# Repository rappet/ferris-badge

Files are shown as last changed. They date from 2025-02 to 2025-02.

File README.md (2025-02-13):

# Ferris STM32L0 badge

Small badge running on a coin cell using a STM32L031G6U with embassy.

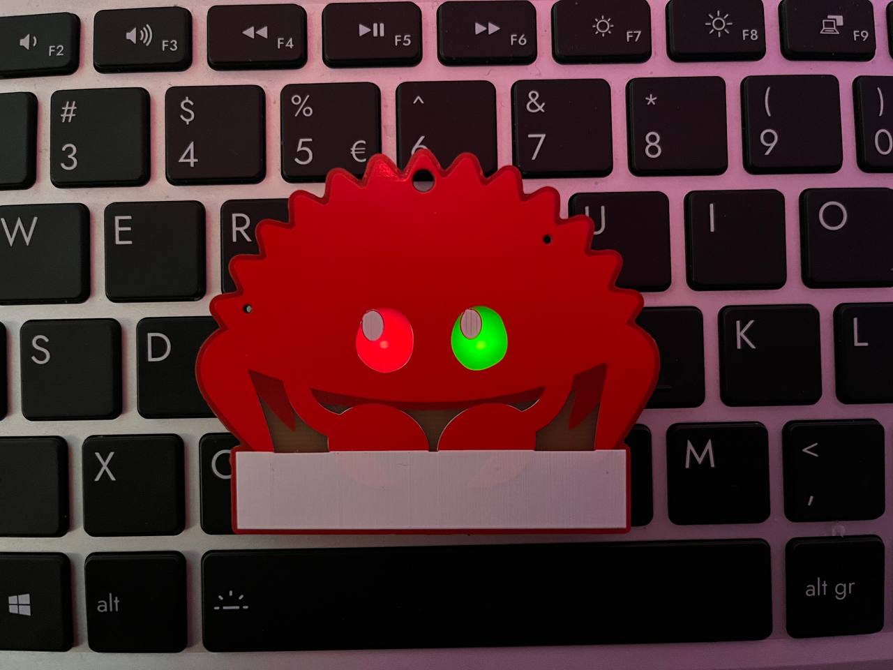
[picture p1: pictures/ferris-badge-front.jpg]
Ferris Badge front picture

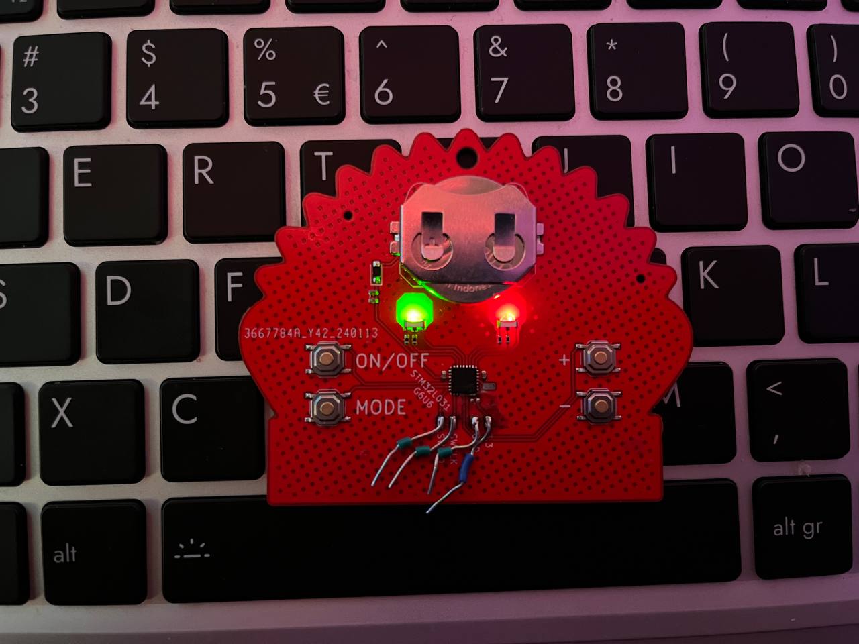
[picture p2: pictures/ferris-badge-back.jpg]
Ferris Badge back picture


## Known bugs

- BOOT0 is not connected
- Reverse polarity protection diode should be swapped with MOSFET
- Output caps could be larger to minimize peak current during PWM
- Shutdown microcontroller with external MOSFET
  - Current power consumption when turned off was measured at ~16µF

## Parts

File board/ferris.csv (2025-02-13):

# | Reference | Qty | Value | Footprint | DNP
1 | BT1 | 1 | Battery_Cell | Battery:BatteryHolder_Keystone_3034_1x20mm
2 | C1, C4 | 2 | 4.7u | Capacitor_SMD:C_0402_1005Metric
3 | C5, C6, C7 | 3 | 100n | Capacitor_SMD:C_0402_1005Metric
4 | D1, D2 | 2 | LED_Dual_KKA | LED_SMD:LED_LiteOn_LTST-S326
5 | D3 | 1 | 1N5819WS | Diode_SMD:D_SOD-323_HandSoldering
6 | H1, H2, H3, H4 | 4 | MountingHole_Pad | Connector_Wire:SolderWirePad_1x01_SMD_1x2mm
7 | J1 | 1 | Conn_RST | Connector_Wire:SolderWirePad_1x01_SMD_1x2mm
8 | R1, R2, R3, R4 | 4 | 33R | Resistor_SMD:R_0402_1005Metric
9 | SW1, SW2, SW3, SW4 | 4 | SW_Push | Button_Switch_SMD:SW_Push_1P1T_XKB_TS-1187A
10 | U1 | 1 | STM32L031G6U6 | Package_DFN_QFN:QFN-28_4x4mm_P0.5mm

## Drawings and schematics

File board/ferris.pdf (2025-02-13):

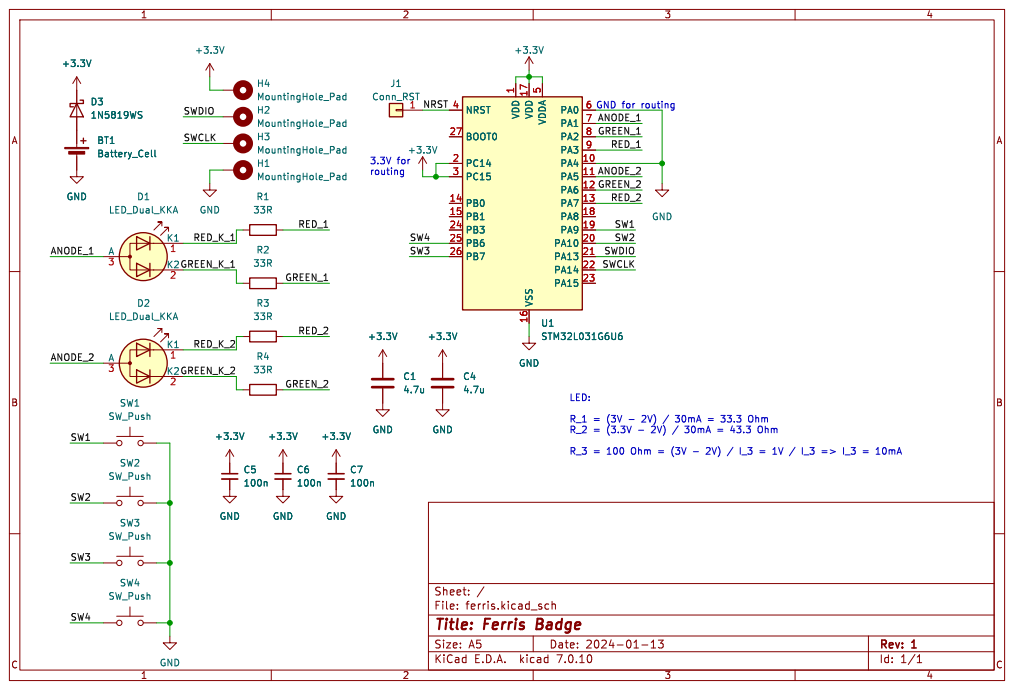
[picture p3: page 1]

1 PA4 10 PA5 11 PA6 12 PA7 13 PB0 14 PB1 15 VSS 16 VDD 17 PA8 18 PA9 19 PC14 2 PA10 20 PA13 21 PA14 22 PA15 23 PB3 24 PB6 25 PB7 26 BOOT0 27 PC15 3 NRST 4 VDDA
U1STM32L031G6U6 VDD

Id: 1/1 Title: Ferris Badge

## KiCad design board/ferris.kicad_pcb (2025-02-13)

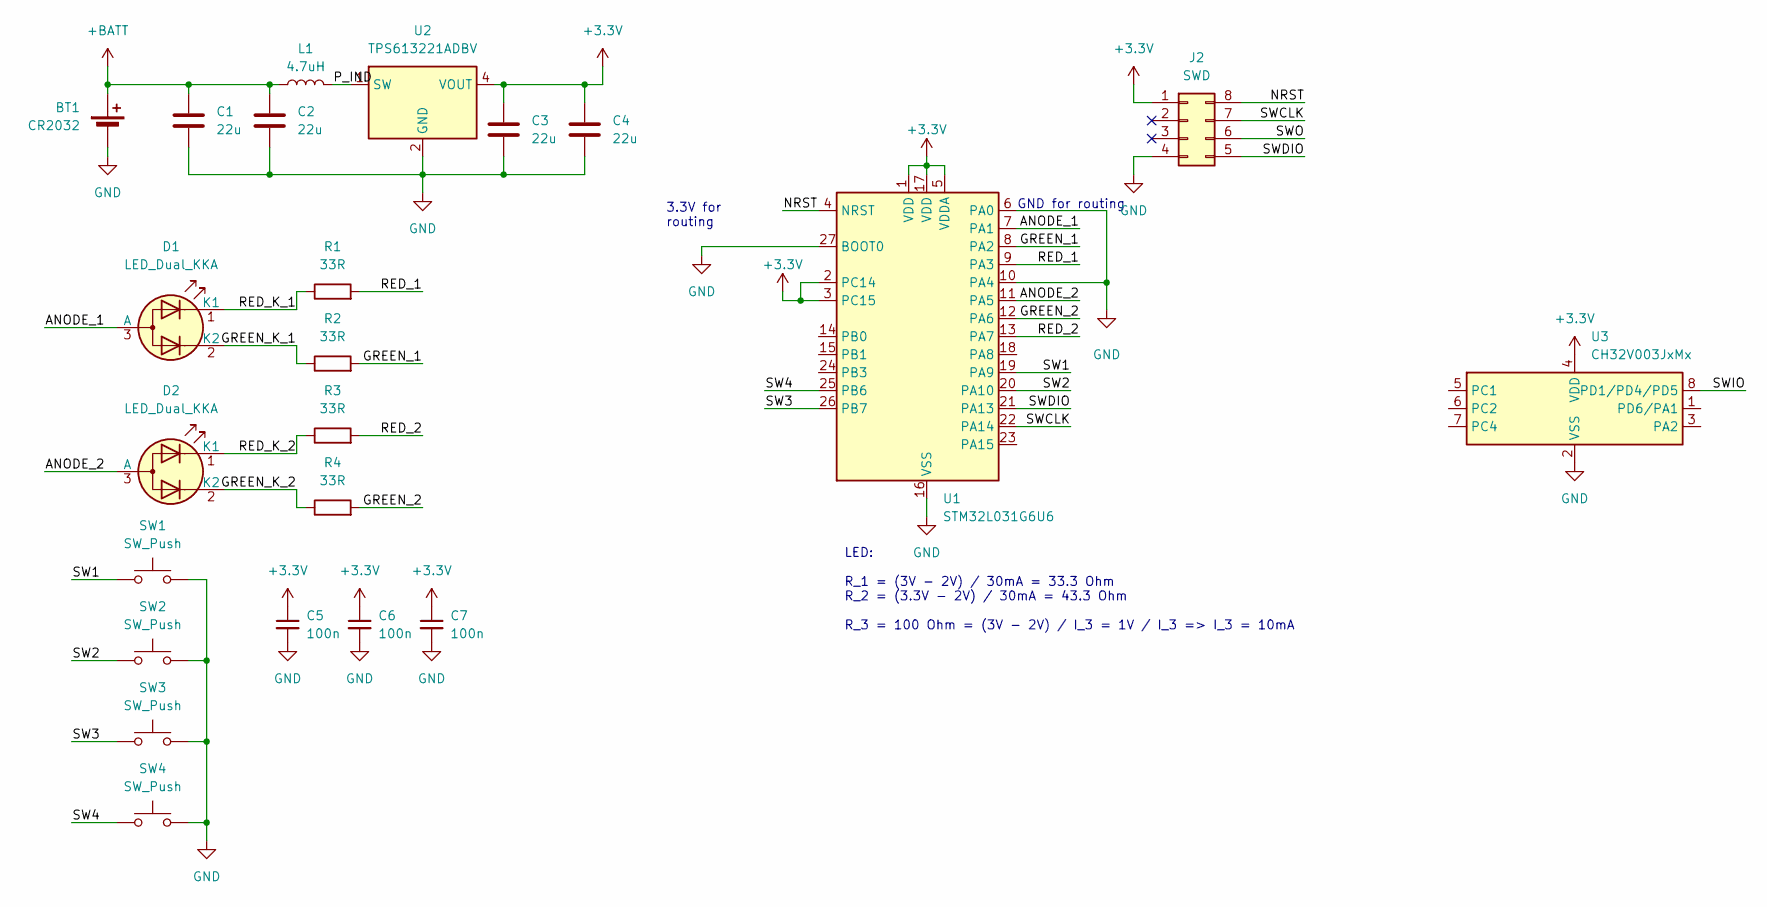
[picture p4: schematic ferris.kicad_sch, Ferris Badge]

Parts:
BT1: CR2032; BatteryHolder_Keystone_3034_1x20mm; LCSC C964833
C1, C2, C3, C4: 22u; C_0805_2012Metric_Pad1.18x1.45mm_HandSolder
C5, C6, C7: 100n; C_0402_1005Metric
D1, D2: LED_Dual_KKA; LED_LiteOn_LTST-S326
J2: SWD; SOIC_clipProgSmall
L1: 4.7uH; L_1008_2520Metric_Pad1.43x2.20mm_HandSolder
R1, R2, R3, R4: 33R; R_0402_1005Metric
SW1, SW2, SW3, SW4: SW_Push; SW_Push_1P1T_XKB_TS-1187A
U1: STM32L031G6U6; QFN-28_4x4mm_P0.5mm
U2: TPS613221ADBV; SOT-23-5_HandSoldering
U3: CH32V003JxMx; SOP-8_3.9x4.9mm_P1.27mm

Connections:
+3.3V: C3.1, C4.1, C5.1, C6.1, C7.1, J2.1, U1.1 (VDD), U1.2 (PC14), U1.3 (PC15), U1.5 (VDDA), U1.17 (VDD), U2.4 (VOUT), U3.4 (VDD)
+BATT: BT1.1 (+), C1.1, C2.1, L1.1
/ANODE_1: D1.3 (A), U1.7 (PA1)
/ANODE_2: D2.3 (A), U1.11 (PA5)
/GREEN_1: R2.2, U1.8 (PA2)
/GREEN_2: R4.2, U1.12 (PA6)
/GREEN_K_1: D1.2 (K2), R2.1
/GREEN_K_2: D2.2 (K2), R4.1
/NRST: J2.8, U1.4 (NRST)
/P_IND: L1.2, U2.1 (SW)
/RED_1: R1.2, U1.9 (PA3)
/RED_2: R3.2, U1.13 (PA7)
/RED_K_1: D1.1 (K1), R1.1
/RED_K_2: D2.1 (K1), R3.1
/SW1: SW1.1, U1.19 (PA9)
/SW2: SW2.1, U1.20 (PA10)
/SW3: SW3.1, U1.26 (PB7)
/SW4: SW4.1, U1.25 (PB6)
/SWCLK: J2.7, U1.22 (PA14)
/SWDIO: J2.5, U1.21 (PA13)
/SWIO: U3.8 (PD1/PD4/PD5)
/SWO: J2.6
GND: BT1.2 (-), C1.2, C2.2, C3.2, C4.2, C5.2, C6.2, C7.2, J2.4, SW1.2, SW2.2, SW3.2, SW4.2, U1.6 (PA0), U1.10 (PA4), U1.16 (VSS), U1.27 (BOOT0), U1.28 (VSS), U2.2 (GND), U3.2 (VSS)

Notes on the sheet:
3.3V for routing
LED: R_1 = (3V - 2V) / 30mA = 33.3 Ohm R_2 = (3.3V - 2V) / 30mA = 43.3 Ohm R_3 = 100 Ohm = (3V - 2V) / I_3 = 1V / I_3 => I_3 = 10mA
GND for routing

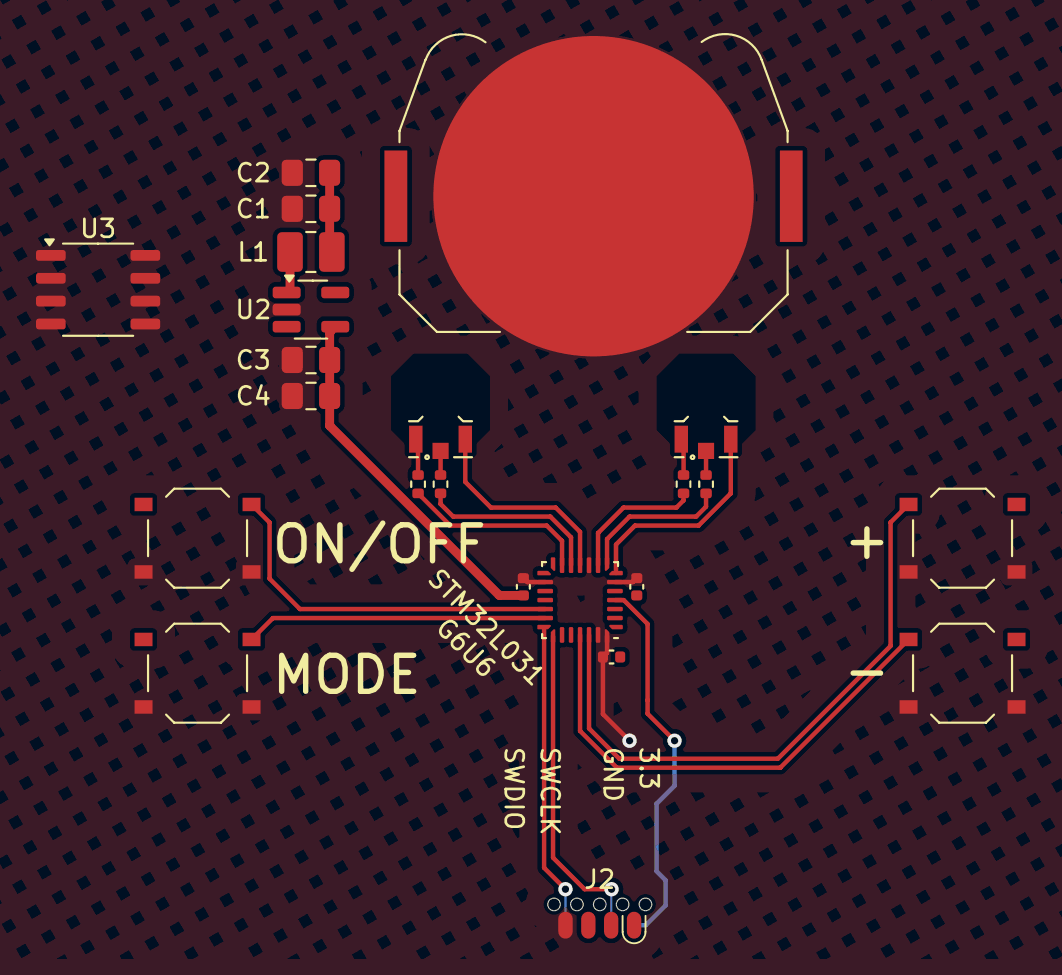
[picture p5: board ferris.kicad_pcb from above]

Board: 2 copper layers, 23 parts (0 on the bottom side), 21 nets.

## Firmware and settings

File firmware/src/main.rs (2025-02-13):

#![no_std]
#![no_main]

mod button;
mod eye;

use defmt::*;
use defmt_rtt as _;
use embassy_executor::Spawner;
use embassy_stm32::{
    exti::ExtiInput,
    gpio::{Input, Level, Output, OutputType, Pull, Speed},
    low_power::{stop_ready, Executor, StopMode},
    peripherals::{IWDG, TIM21, TIM22},
    rcc::{self, MSIRange, VoltageScale},
    rtc::{Rtc, RtcConfig},
    time::Hertz,
    timer::{
        low_level::CountingMode,
        simple_pwm::{PwmPin, SimplePwm, SimplePwmChannel},
    },
    wdg::IndependentWatchdog,
    Config,
};
use embassy_time::{Instant, Timer};
use panic_halt as _;
use static_cell::StaticCell;

use crate::{button::Button, eye::Eye};

const PWM_FREQUENCY: Hertz = Hertz::hz(4096 * 4);

#[cortex_m_rt::entry]
fn main() -> ! {
    Executor::take().run(|spawner| {
        spawner.spawn(async_main(spawner)).unwrap();
    });
}

#[embassy_executor::task]
async fn async_main(_spawner: Spawner) {
    let p = embassy_stm32::init({
        let mut config = Config::default();
        config.rcc = rcc::Config {
            msi: Some(MSIRange::RANGE4M),
            voltage_scale: VoltageScale::RANGE1,
            ..rcc::Config::default()
        };
        config.enable_debug_during_sleep = false;
        config
    });

    let rtc = Rtc::new(p.RTC, RtcConfig::default());
    static RTC: StaticCell<Rtc> = StaticCell::new();
    let rtc = RTC.init(rtc);
    embassy_stm32::low_power::stop_with_rtc(rtc);

    info!("Started 🦀");

    let mut btn_on = ExtiInput::new(p.PA9, p.EXTI9, Pull::Up);

    info!("Waiting for on!");
    info!("Low power mode enabled: {}", stop_ready(StopMode::Stop2));

    btn_on.wait_for_low().await;

    let mut good_boy = IndependentWatchdog::new(p.IWDG, 1_000 * 1_000 * 3);
    good_boy.unleash();

    good_boy.pet();

    info!("On!");

    let _anode_1 = Output::new(p.PA1, Level::High, Speed::Low);
    let _anode_2 = Output::new(p.PA5, Level::High, Speed::Low);

    let mut peripherals = {
        Timer::after_millis(1).await;

        let btn_on = Button::new(btn_on);
        let btn_mode = Button::new(Input::new(p.PA10, Pull::Up));

        let green_1 = PwmPin::new_ch1(p.PA2, OutputType::PushPull);
        let red_1 = PwmPin::new_ch2(p.PA3, OutputType::PushPull);
        let mut pwm_1 = SimplePwm::new(
            p.TIM21,
            Some(green_1),
            Some(red_1),
            None,
            None,
            PWM_FREQUENCY,
            CountingMode::EdgeAlignedUp,
        )
        .split();
        pwm_1.ch1.enable();
        pwm_1.ch2.enable();

        let eye_left = Eye::new(pwm_1.ch1, pwm_1.ch2);

        let green_2 = PwmPin::new_ch1(p.PA6, OutputType::PushPull);
        let red_2 = PwmPin::new_ch2(p.PA7, OutputType::PushPull);
        let mut pwm_2 = SimplePwm::new(
            p.TIM22,
            Some(green_2),
            Some(red_2),
            None,
            None,
            PWM_FREQUENCY,
            CountingMode::default(),
        )
        .split();
        pwm_2.ch1.enable();
        pwm_2.ch2.enable();

        let eye_right = Eye::new(pwm_2.ch1, pwm_2.ch2);

        BadgePeripherals {
            eye_left,
            eye_right,
            btn_on,
            btn_mode,
            good_boy,
        }
    };

    let mut mode = Mode::Red;

    loop {
        info!("Activated");

        active_loop(&mut peripherals, &mut mode).await;

        peripherals.eye_left.set_off();
        peripherals.eye_right.set_off();

        while !peripherals.btn_on.is_activated() {
            Timer::after_millis(10).await;
        }
    }
}

async fn active_loop(p: &mut BadgePeripherals<'_>, mode: &mut Mode) {
    let max_value = p.eye_left.max_value();
    info!("{}", max_value);

    while !p.btn_on.is_activated() {
        if p.btn_mode.is_activated() {
            mode.next();
        }
        match *mode {
            Mode::Red => {
                p.eye_left.set_red();
                p.eye_right.set_red();
            }
            Mode::Green => {
                p.eye_left.set_green();
                p.eye_right.set_green();
            }
            Mode::Yellow => {
                p.eye_left.set_value(max_value, max_value);
                p.eye_right.set_value(max_value, max_value);
            }
            Mode::Blink => {
                let now = Instant::now();
                if now.as_millis() % 1000 < 500 {
                    p.eye_left.set_red();
                    p.eye_right.set_green();
                } else {
                    p.eye_left.set_green();
                    p.eye_right.set_red();
                }
            }
            Mode::Fade => {
                let millis = (Instant::now().as_millis() % 4000) as u32;
                let fade = ((millis % 2000) * (max_value as u32) / 2000) as u16;
                if millis < 2000 {
                    p.eye_left.set_value(fade, max_value - fade);
                    p.eye_right.set_value(fade, max_value - fade);
                } else {
                    p.eye_left.set_value(max_value - fade, fade);
                    p.eye_right.set_value(max_value - fade, fade);
                }
            }
        }

        p.good_boy.pet();
        Timer::after_millis(1).await;
    }
    info!("Deactivated")
}

pub struct BadgePeripherals<'d> {
    pub eye_left: Eye<SimplePwmChannel<'d, TIM21>, SimplePwmChannel<'d, TIM21>>,
    pub eye_right: Eye<SimplePwmChannel<'d, TIM22>, SimplePwmChannel<'d, TIM22>>,
    pub btn_on: Button<ExtiInput<'d>>,
    pub btn_mode: Button<Input<'d>>,
    pub good_boy: IndependentWatchdog<'d, IWDG>,
}

pub enum Mode {
    Red,
    Green,
    Yellow,
    Blink,
    Fade,
}

impl Mode {
    pub fn next(&mut self) {
        *self = match *self {
            Mode::Red => Mode::Green,
            Mode::Green => Mode::Yellow,
            Mode::Yellow => Mode::Blink,
            Mode::Blink => Mode::Fade,
            Mode::Fade => Mode::Red,
        }
    }
}

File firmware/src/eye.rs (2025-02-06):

use embedded_hal::pwm::SetDutyCycle;

pub struct Eye<A: SetDutyCycle, B: SetDutyCycle>(A, B);

impl<A: SetDutyCycle, B: SetDutyCycle> Eye<A, B> {
    pub fn new(pwm_red: A, pwm_green: B) -> Self {
        let mut eye = Self(pwm_red, pwm_green);
        eye.set_off();
        eye
    }

    pub fn set_off(&mut self) {
        self.0.set_duty_cycle(self.0.max_duty_cycle()).ok();
        self.1.set_duty_cycle(self.1.max_duty_cycle()).ok();
    }

    pub fn set_green(&mut self) {
        self.set_value(0, self.max_value());
    }

    pub fn set_red(&mut self) {
        self.set_value(self.max_value(), 0);
    }

    pub fn set_value(&mut self, red: u16, green: u16) {
        self.0.set_duty_cycle(self.max_value() - green).ok();
        // red is _really_ bright
        self.1.set_duty_cycle(self.max_value() - (red >> 3)).ok();
    }

    pub fn max_value(&self) -> u16 {
        self.0.max_duty_cycle()
    }
}

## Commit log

2025-02-06 pwm: Use more abstractions
2025-02-06 Remove panic-probe with panic-halt
    This shrinks the code size so much, that the firmware fits into a 16kb
    flash.
2025-02-13 Switch from probe-run to probe-rs run
2025-02-13 Fix low power mode
    [main.rs]
2025-02-13 Increase LED PWM frequency by a large margin
2025-02-13 Add hardware
    [ferris-B_Cu.gbr, ferris-B_Mask.gbr, ferris-B_Paste.gbr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]
